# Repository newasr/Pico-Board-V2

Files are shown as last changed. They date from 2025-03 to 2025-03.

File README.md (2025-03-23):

# Pico-Board-V2
PICO Board v1 : [Github Link](http://github.com/newasr/Pico-board)

Changes:
- Resolved DRC and ERC which were there in v1.
- Added the Raspberry Pi logo for a more authentic look.
- Standardized component names to be horizontally aligned for a cleaner and more readable design.

# Schematic
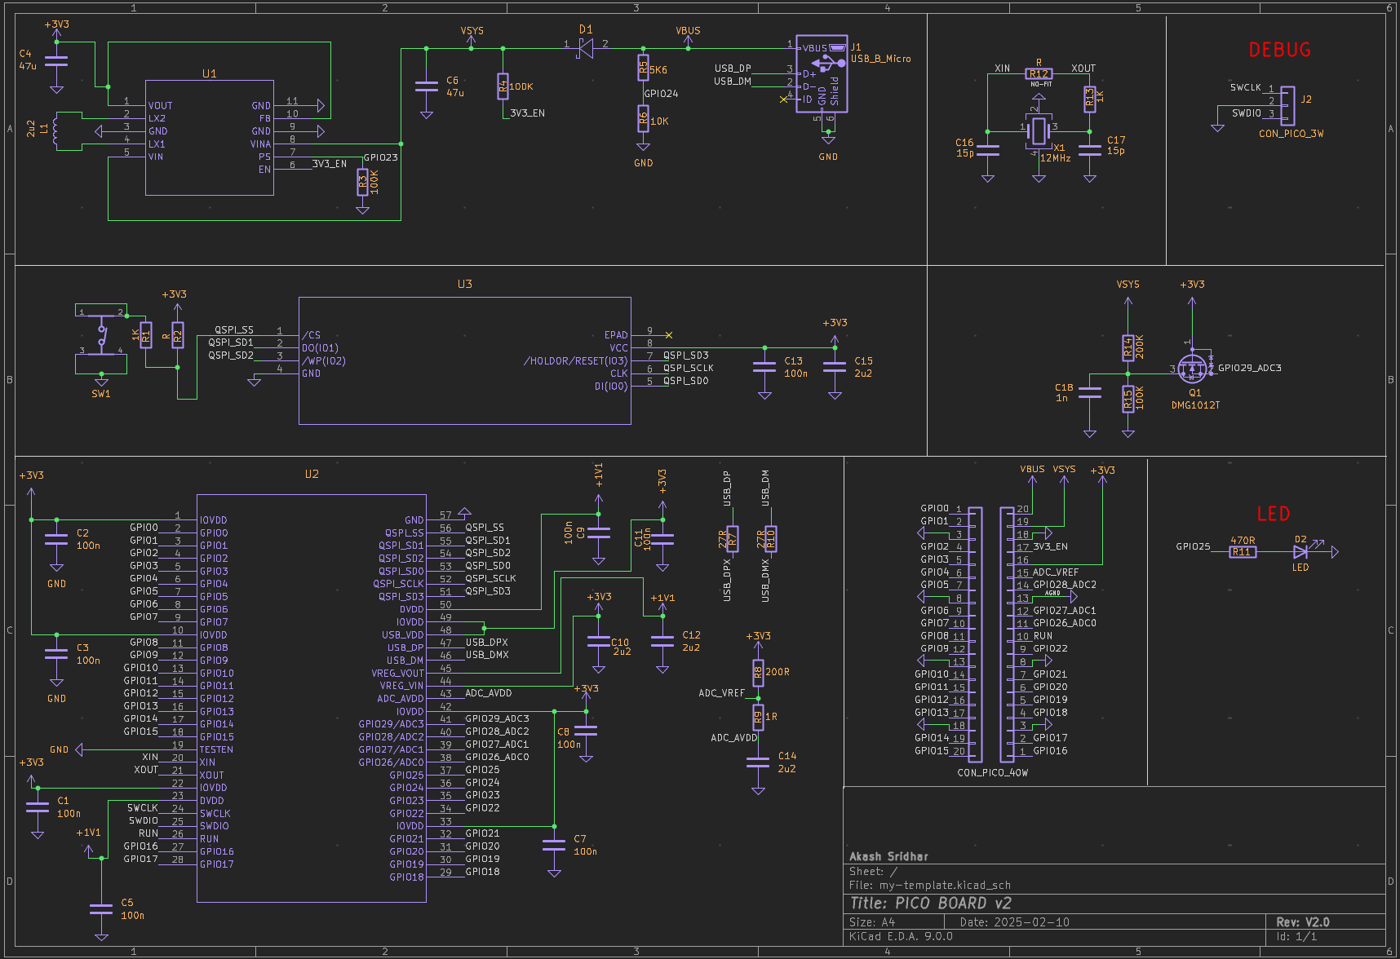
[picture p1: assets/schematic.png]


# 3D View
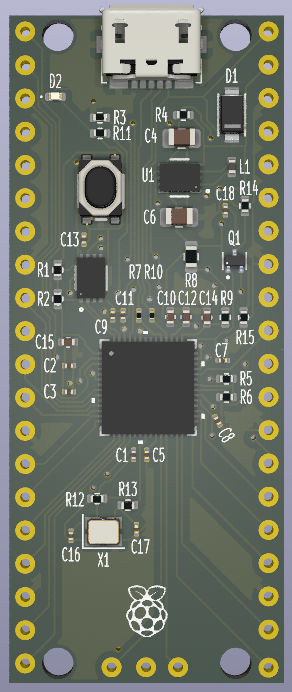
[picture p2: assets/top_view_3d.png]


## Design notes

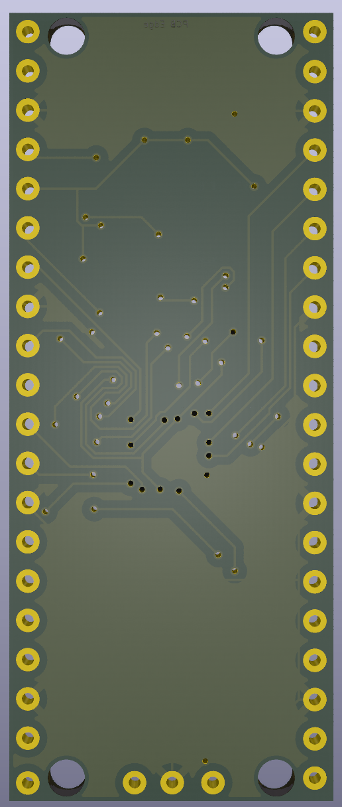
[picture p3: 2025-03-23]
assets/bottom_view_3d.png

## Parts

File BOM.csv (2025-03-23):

References | Value | Footprint | Quantity
C1, C2, C3, C5, C7, C8, C9, C11, C13 | 100n | C_0201_0603Metric | 9
C10, C12, C14, C15 | 2u2 | C_0402_1005Metric | 4
C4, C6 | 47u | C_0805_2012Metric | 2
C16, C17 | 15p | C_0201_0603Metric | 2
C18 | 1n | C_0201_0603Metric | 1
R3, R4, R15 | 100K | R_0402_1005Metric | 3
R1, R13 | 1K | R_0402_1005Metric | 2
R2, R12 | R | R_0402_1005Metric | 2
R7, R10 | 27R | R_0201_0603Metric | 2
R5 | 5K6 | R_0402_1005Metric | 1
R6 | 10K | R_0402_1005Metric | 1
R8 | 200R | R_0603_1608Metric | 1
R9 | 1R | R_0402_1005Metric | 1
R11 | 470R | R_0402_1005Metric | 1
R14 | 200K | R_0402_1005Metric | 1
L1 | 2u2 | L_0402_1005Metric | 1
D1 | MBR120VLSFT1G | MBR120VLSFT1G | 1
D2 | LED | LED_0402_1005Metric | 1
U1 | RT6150B-33GQW | RT6150B-33GQW | 1
U2 | SC09147 | QFN56_7X7_RPI | 1
U3 | W25Q16JVUXIQ TR | W25Q16JVUXIQ_TR | 1
X1 | 12MHz | Oscillator_SMD_SeikoEpson_SG210-4Pin_2.5x2.0mm | 1
SW1 | 434133025816 | 434133025816 | 1
40_part1 | Conn_01x20 | part_1_40_pin | 1
40_part2 | Conn_01x20 | part_2_40_pin | 1
Q1 | DMG1012T | SOT-523 | 1
J1 | USB_B_Micro | USB_Micro-B_Molex_47346-0001 | 1
J2 | CON_PICO_3W | 3_pin_connector | 1

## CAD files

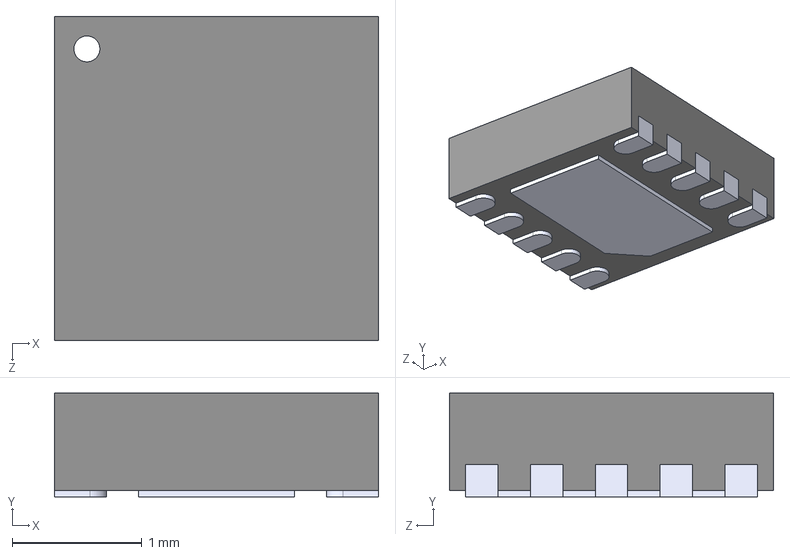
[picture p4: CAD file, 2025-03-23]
hardware/3d-models/RT6150B-33GQW.step
2.50 x 0.8 x 2.50 mm

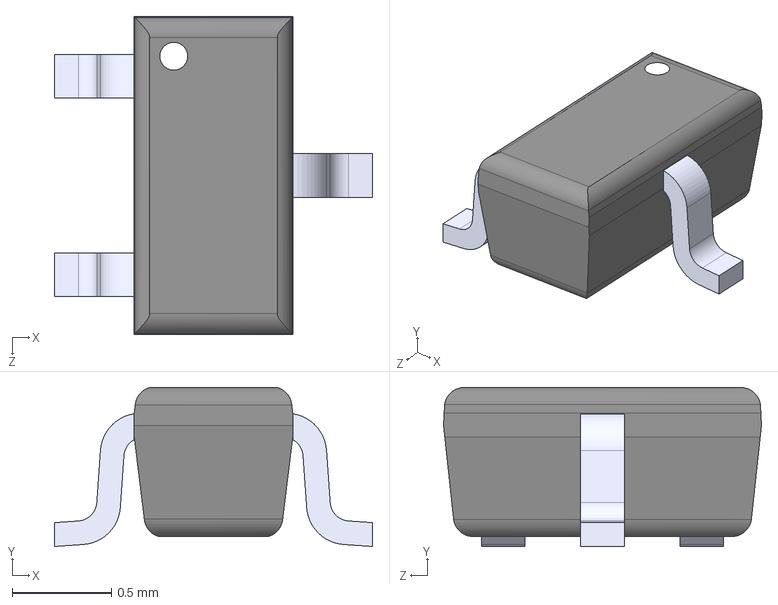
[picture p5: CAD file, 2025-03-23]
hardware/3d-models/DMG1012T-7.step
1.60 x 0.8 x 1.60 mm

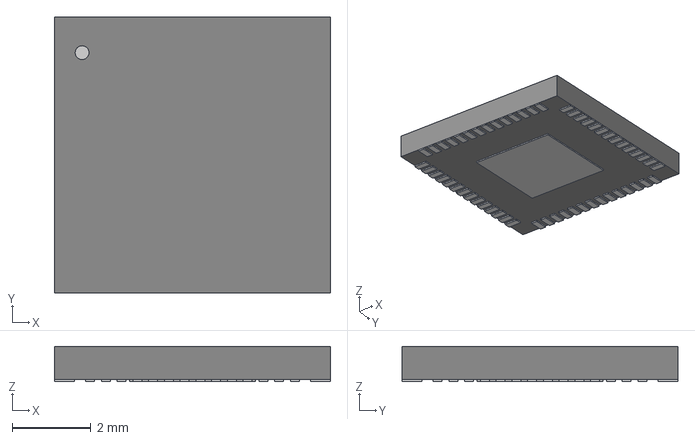
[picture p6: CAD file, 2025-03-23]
hardware/3d-models/QFN56_7X7_RPI.step
7.01 x 7.01 x 0.892 mm

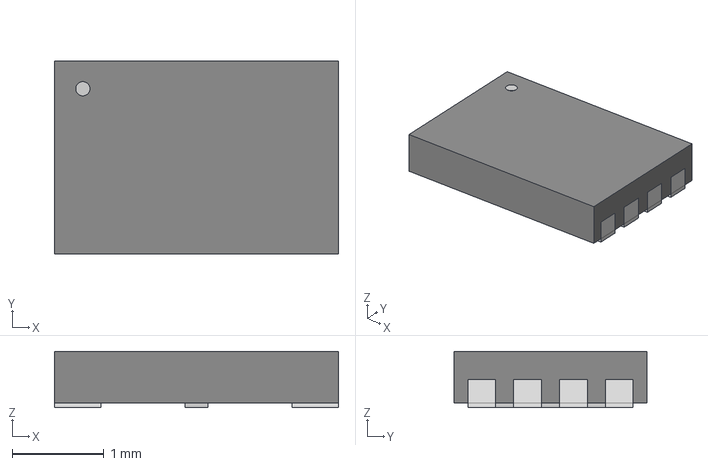
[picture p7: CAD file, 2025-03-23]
hardware/3d-models/W25Q16JVUXIQ_TR.step
3.10 x 2.11 x 0.612 mm

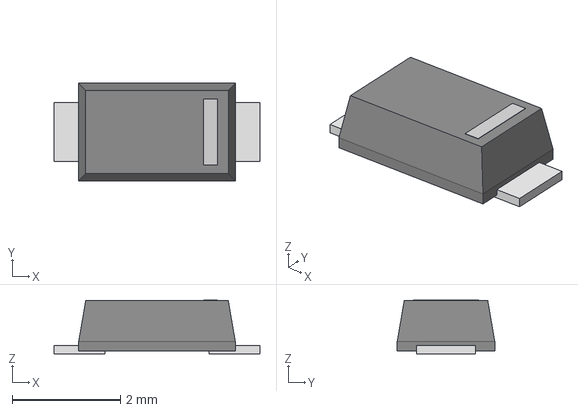
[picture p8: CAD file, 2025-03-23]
hardware/3d-models/MBR120VLSFT1G.step
3.81 x 1.80 x 0.997 mm

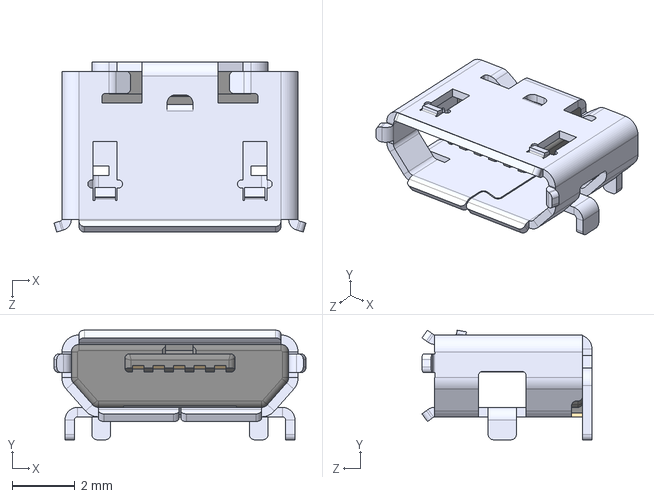
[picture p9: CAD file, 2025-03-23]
hardware/3d-models/1050170001.step
8.00 x 3.48 x 5.40 mm

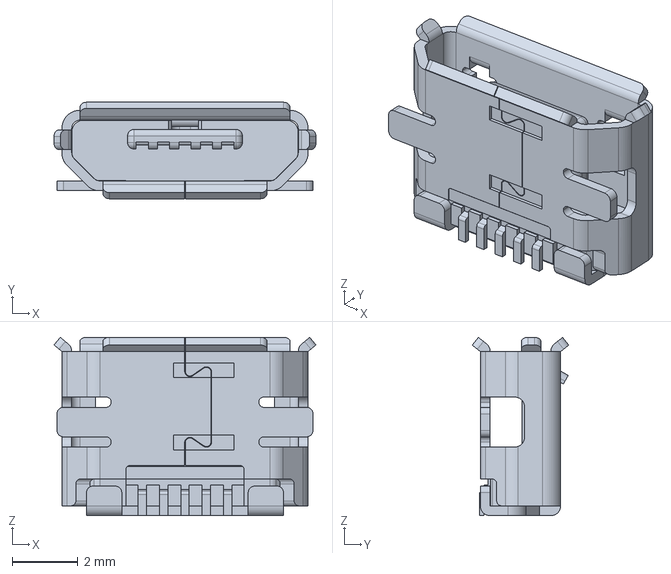
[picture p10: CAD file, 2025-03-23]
hardware/3d-models/47346-0001.step
7.98 x 2.94 x 5.43 mm

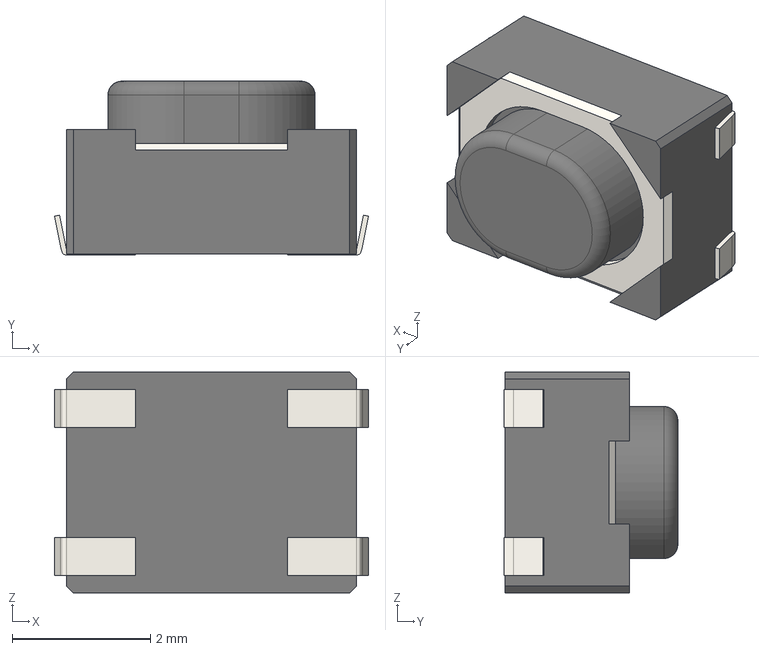
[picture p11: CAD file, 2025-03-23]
hardware/3d-models/434133025816.step
4.55 x 2.52 x 3.20 mm

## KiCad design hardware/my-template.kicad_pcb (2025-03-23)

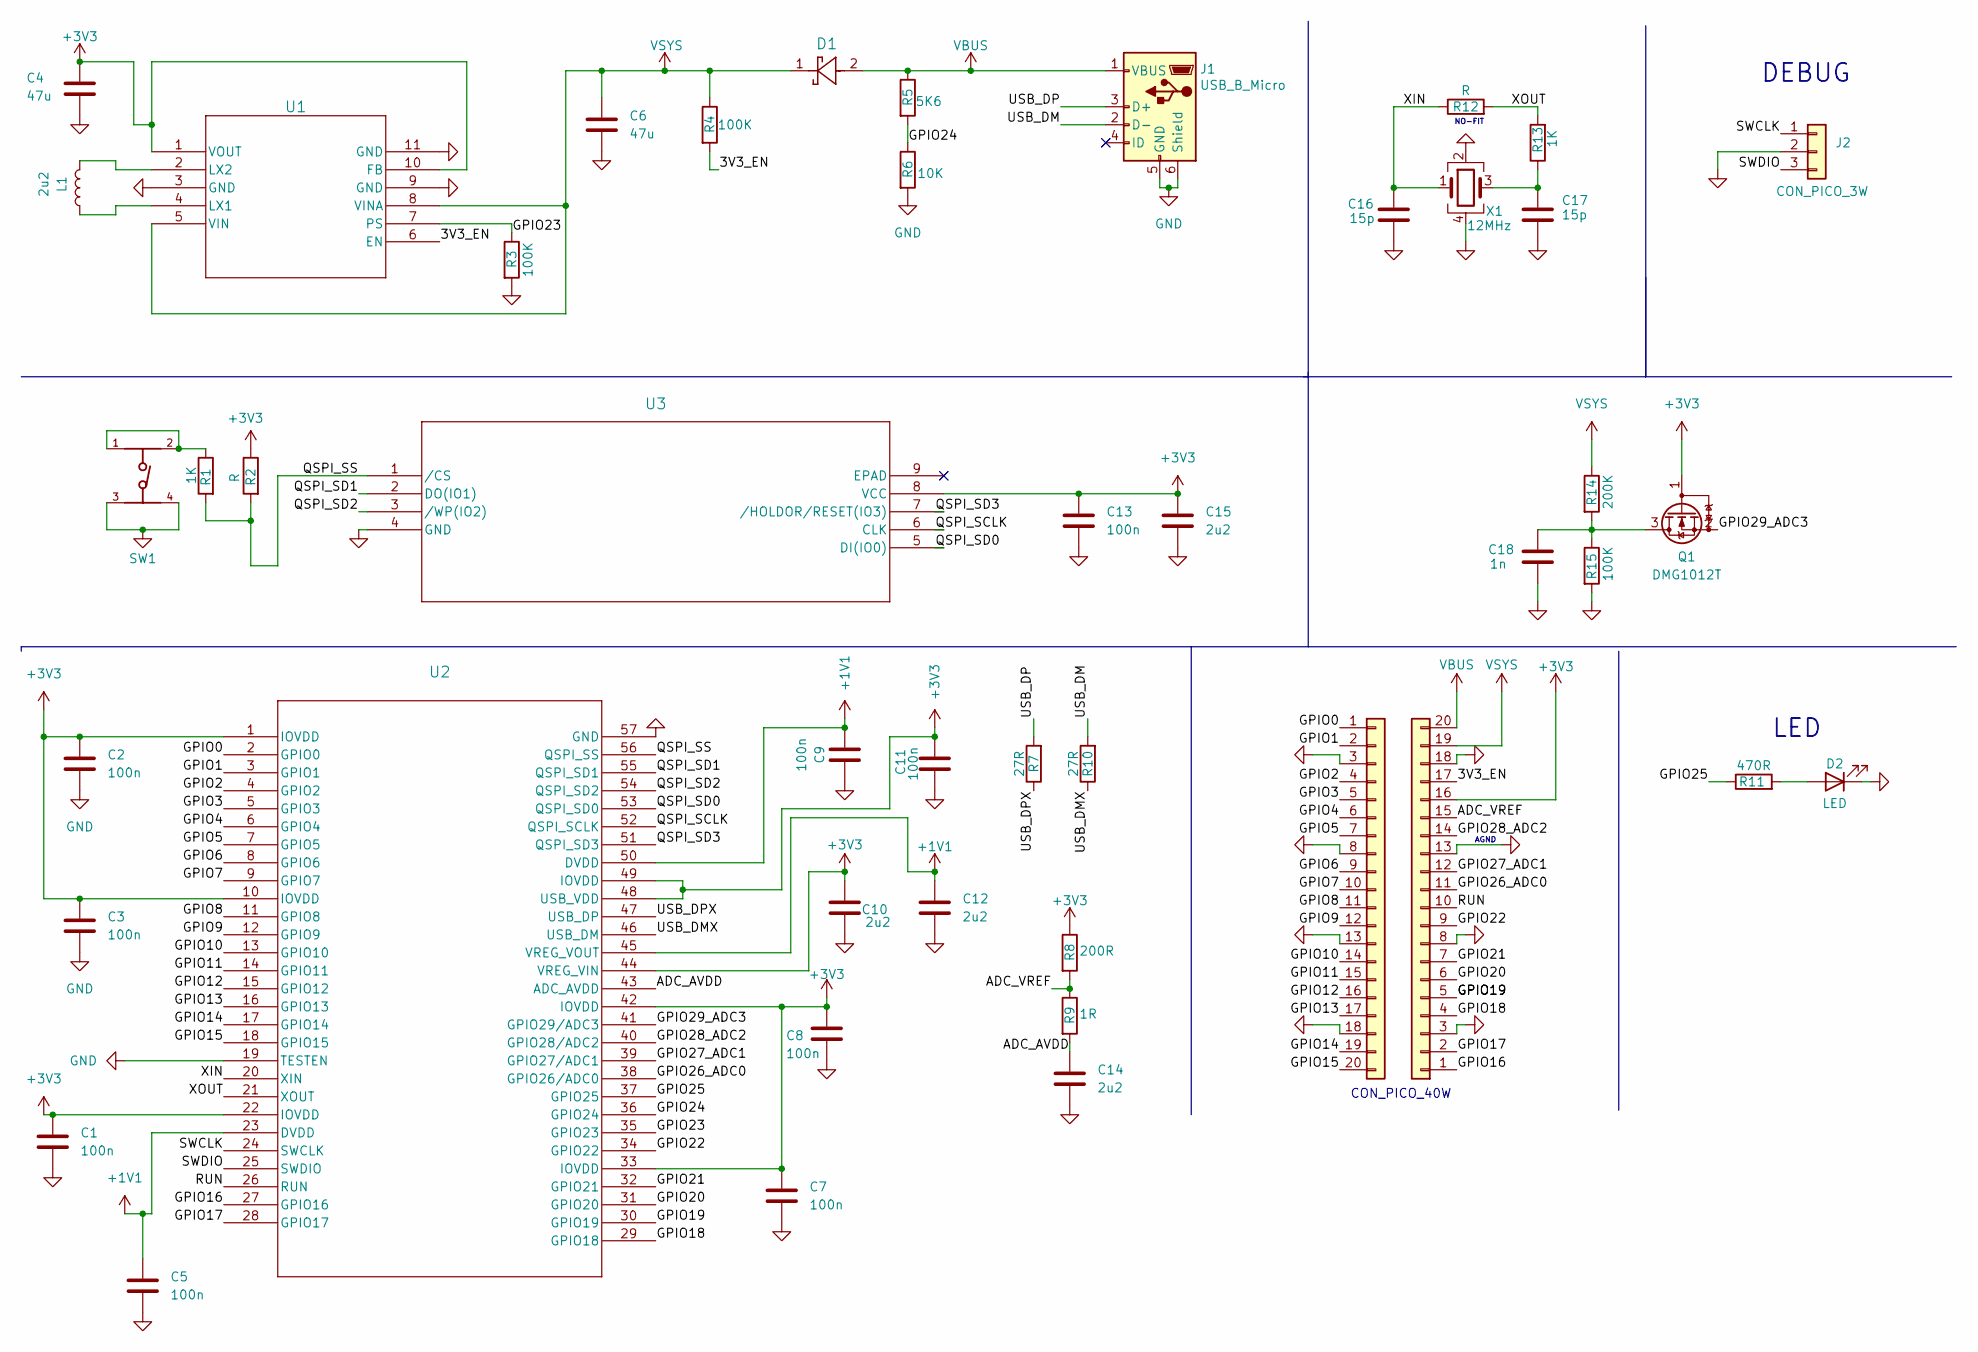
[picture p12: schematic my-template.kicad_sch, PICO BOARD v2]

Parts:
C1, C2, C3, C5, C7, C8, C9, C11, C13: 100n; C_0201_0603Metric; Digikey Part# CL03A104KQ3NNNC
C4, C6: 47u; C_0805_2012Metric; Digikey Part# CL21A476MQYNNNE
C10, C12, C14, C15: 2u2; C_0402_1005Metric; Digikey Part# CL05A225MQ5NNNC
C16, C17: 15p; C_0201_0603Metric; Digikey Part# GRM0335C1E150JA01D
C18: 1n; C_0201_0603Metric; Digikey Part# KGM05AR70J102MH
D1: MBR120VLSFT1G; Digikey Part# MBR120VLSFT1G
D2: LED; LED_0402_1005Metric; Digikey Part# 150040GS73240
J1: USB_B_Micro; USB_Micro-B_Molex_47346-0001; Digikey Part# 0473460001
J2: CON_PICO_3W; 3_pin_connector
J3: Conn_01x20; part_1_40_pin
J4: Conn_01x20; part_2_40_pin
L1: 2u2; L_0402_1005Metric; Digikey Part# MLZ1005M2R2WT000
Q1: DMG1012T; SOT-523; Digikey Part# DMG1012T-7
R1, R13: 1K; R_0402_1005Metric; Digikey Part# RK73H1ETTP1001F
R2, R12: R; R_0402_1005Metric
R3, R4, R15: 100K; R_0402_1005Metric; Digikey Part# RK73H1ETTP1003F
R5: 5K6; R_0402_1005Metric; Digikey Part# ERJ-2RKF5601X
R6: 10K; R_0402_1005Metric; Digikey Part# RK73H1ETTP1002F
R7, R10: 27R; R_0201_0603Metric; Digikey Part# RK73H1ETTP27R0F
R8: 200R; R_0603_1608Metric; Digikey Part# CRCW0603200RFKEAC
R9: 1R; R_0402_1005Metric; Digikey Part# RK73H1ETTP1R00F
R11: 470R; R_0402_1005Metric; Digikey Part# RK73H1ETTP4700F
R14: 200K; R_0402_1005Metric; Digikey Part# RK73H1ETTP2003F
SW1: 434133025816; PART-NUMBER 434133025816; Digikey Part# 434133025816
U1: RT6150B-33GQW; Digikey Part# RT6150B-33GQW
U2: SC09147; QFN56_7X7_RPI; Digikey Part# SC0914(7)
U3: W25Q16JVUXIQ TR; W25Q16JVUXIQ_TR; Digikey Part# W25Q16JVUXIQ TR
X1: 12MHz; Oscillator_SMD_SeikoEpson_SG210-4Pin_2.5x2.0mm; Digikey Part# ECS-2520MVLC-120-CN-TR

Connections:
+1V1: C5.1, C9.2, C12.1, U2.23 (DVDD), U2.45 (VREG_VOUT), U2.50 (DVDD)
+3V3: C1.1, C2.1, C3.1, C4.1, C7.1, C8.1, C10.1, C11.1, C13.1, C15.1, J4.16, Q1.1 (G), R2.1, R8.1, U1.1 (VOUT), U1.10 (FB), U2.1 (IOVDD), U2.10 (IOVDD), U2.22 (IOVDD), U2.33 (IOVDD), U2.42 (IOVDD), U2.44 (VREG_VIN), U2.48 (USB_VDD), U2.49 (IOVDD), U3.8 (VCC); also elsewhere on the board
/3V3_EN: J4.17, R4.2, U1.6 (EN); also elsewhere on the board
/ADC_AVDD: C14.1, R9.2, U2.43 (ADC_AVDD)
/ADC_VREF: J4.15, R8.2, R9.1; also elsewhere on the board
/GPIO0: J3.1, U2.2 (GPIO0); also elsewhere on the board
/GPIO1: J3.2, U2.3 (GPIO1); also elsewhere on the board
/GPIO2: J3.4, U2.4 (GPIO2); also elsewhere on the board
/GPIO3: J3.5, U2.5 (GPIO3); also elsewhere on the board
/GPIO4: J3.6, U2.6 (GPIO4); also elsewhere on the board
/GPIO5: J3.7, U2.7 (GPIO5); also elsewhere on the board
/GPIO6: J3.9, U2.8 (GPIO6); also elsewhere on the board
/GPIO7: J3.10, U2.9 (GPIO7); also elsewhere on the board
/GPIO8: J3.11, U2.11 (GPIO8); also elsewhere on the board
/GPIO9: J3.12, U2.12 (GPIO9); also elsewhere on the board
/GPIO10: J3.14, U2.13 (GPIO10); also elsewhere on the board
/GPIO11: J3.15, U2.14 (GPIO11); also elsewhere on the board
/GPIO12: J3.16, U2.15 (GPIO12); also elsewhere on the board
/GPIO13: J3.17, U2.16 (GPIO13); also elsewhere on the board
/GPIO14: J3.19, U2.17 (GPIO14); also elsewhere on the board
/GPIO15: J3.20, U2.18 (GPIO15); also elsewhere on the board
/GPIO16: J4.1, U2.27 (GPIO16); also elsewhere on the board
/GPIO17: J4.2, U2.28 (GPIO17); also elsewhere on the board
/GPIO18: J4.4, U2.29 (GPIO18); also elsewhere on the board
/GPIO19: J4.5, U2.30 (GPIO19); also elsewhere on the board
/GPIO20: J4.6, U2.31 (GPIO20); also elsewhere on the board
/GPIO21: J4.7, U2.32 (GPIO21); also elsewhere on the board
/GPIO22: J4.9, U2.34 (GPIO22); also elsewhere on the board
/GPIO23: R3.1, U1.7 (PS), U2.35 (GPIO23)
/GPIO24: R5.2, R6.1, U2.36 (GPIO24)
/GPIO25: R11.1, U2.37 (GPIO25)
/GPIO26_ADC0: J4.11, U2.38 (GPIO26/ADC0); also elsewhere on the board
/GPIO27_ADC1: J4.12, U2.39 (GPIO27/ADC1); also elsewhere on the board
/GPIO28_ADC2: J4.14, U2.40 (GPIO28/ADC2); also elsewhere on the board
/GPIO29_ADC3: Q1.2 (S), U2.41 (GPIO29/ADC3)
/QSPI_SCLK: U2.52 (QSPI_SCLK), U3.6 (CLK)
/QSPI_SD0: U2.53 (QSPI_SD0), U3.5 (DI(IO0))
/QSPI_SD1: U2.55 (QSPI_SD1), U3.2 (DO(IO1))
/QSPI_SD2: U2.54 (QSPI_SD2), U3.3 (/WP(IO2))
/QSPI_SD3: U2.51 (QSPI_SD3), U3.7 (/HOLDOR/RESET(IO3))
/QSPI_SS: R1.2, R2.2, U2.56 (QSPI_SS), U3.1 (/CS)
/RUN: J4.10, U2.26 (RUN); also elsewhere on the board
/SWCLK: J2.1, U2.24 (SWCLK)
/SWDIO: J2.3, U2.25 (SWDIO)
/USB_DM: J1.2 (D-), R10.2
/USB_DMX: R10.1, U2.46 (USB_DM)
/USB_DP: J1.3 (D+), R7.2
/USB_DPX: R7.1, U2.47 (USB_DP)
/XIN: C16.1, R12.1, U2.20 (XIN), X1.1
/XOUT: R12.2, R13.2, U2.21 (XOUT)
GND: C1.2, C2.2, C3.2, C4.2, C5.2, C6.2, C7.2, C8.2, C9.1, C10.2, C11.2, C12.2, C13.2, C14.2, C15.2, C16.2, C17.2, C18.2, D2.1 (K), J1.5 (GND), J1.6 (Shield), J2.2, J3.3, J3.8, J3.13, J3.18, J4.3, J4.8, J4.13, J4.18, R3.2, R6.2, R15.2, SW1.3, SW1.4, U1.3 (GND), U1.9 (GND), U1.11 (GND), U2.19 (TESTEN), U2.57 (GND), U3.4 (GND), X1.2, X1.4; also elsewhere on the board
unnamed: C17.1, R13.1, X1.3
unnamed: D2.2 (A), R11.2
unnamed: C18.1, Q1.3 (D), R14.2, R15.1
unnamed: R1.1, SW1.1, SW1.2
unnamed: L1.1, U1.4 (LX1)
unnamed: L1.2, U1.2 (LX2)
VBUS: D1.2, J1.1 (VBUS), J4.20, R5.1; also elsewhere on the board
VSYS: C6.1, D1.1, J4.19, R4.1, R14.1, U1.5 (VIN), U1.8 (VINA); also elsewhere on the board

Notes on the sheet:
LED
CON_PICO_40W
AGND
DEBUG
NO-FIT

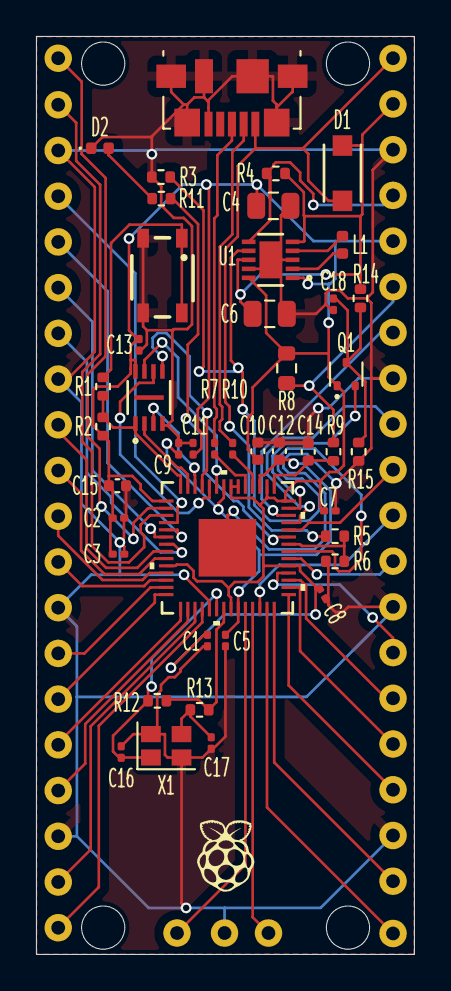
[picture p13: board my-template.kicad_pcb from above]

Board: 2 copper layers, 21.0 x 51.0 mm, 46 parts (0 on the bottom side), 59 nets.

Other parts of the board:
40_part1: Conn_01x20; part_1_40_pin
40_part2: Conn_01x20; part_2_40_pin

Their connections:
+3V3: 40_part2.16; also elsewhere on the board
/3V3_EN: 40_part2.17; also elsewhere on the board
/ADC_VREF: 40_part2.15; also elsewhere on the board
/GPIO0: 40_part1.1; also elsewhere on the board
/GPIO1: 40_part1.2; also elsewhere on the board
/GPIO2: 40_part1.4; also elsewhere on the board
/GPIO3: 40_part1.5; also elsewhere on the board
/GPIO4: 40_part1.6; also elsewhere on the board
/GPIO5: 40_part1.7; also elsewhere on the board
/GPIO6: 40_part1.9; also elsewhere on the board
/GPIO7: 40_part1.10; also elsewhere on the board
/GPIO8: 40_part1.11; also elsewhere on the board
/GPIO9: 40_part1.12; also elsewhere on the board
/GPIO10: 40_part1.14; also elsewhere on the board
/GPIO11: 40_part1.15; also elsewhere on the board
/GPIO12: 40_part1.16; also elsewhere on the board
/GPIO13: 40_part1.17; also elsewhere on the board
/GPIO14: 40_part1.19; also elsewhere on the board
/GPIO15: 40_part1.20; also elsewhere on the board
/GPIO16: 40_part2.1; also elsewhere on the board
/GPIO17: 40_part2.2; also elsewhere on the board
/GPIO18: 40_part2.4; also elsewhere on the board
/GPIO19: 40_part2.5; also elsewhere on the board
/GPIO20: 40_part2.6; also elsewhere on the board
/GPIO21: 40_part2.7; also elsewhere on the board
/GPIO22: 40_part2.9; also elsewhere on the board
/GPIO26_ADC0: 40_part2.11; also elsewhere on the board
/GPIO27_ADC1: 40_part2.12; also elsewhere on the board
/GPIO28_ADC2: 40_part2.14; also elsewhere on the board
/RUN: 40_part2.10; also elsewhere on the board
GND: 40_part1.3, 40_part1.8, 40_part1.13, 40_part1.18, 40_part2.3, 40_part2.8, 40_part2.13, 40_part2.18; also elsewhere on the board
VBUS: 40_part2.20; also elsewhere on the board
VSYS: 40_part2.19; also elsewhere on the board

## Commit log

2025-03-23 added schematic and 3d images
2025-03-23 added hardware files and bom
    [1050170001.step, 434133025816.step, 47346-0001.step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]
